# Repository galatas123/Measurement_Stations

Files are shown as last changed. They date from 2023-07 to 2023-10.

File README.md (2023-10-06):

# Measurement_Stations

Features:

   . CO2 Monitoring: Efficiently measures CO2 concentrations, aiding in maintaining a safe indoor environment during pandemic situations.
    
   . Environmental Conditions: Captures data on temperature, humidity, and air pressure, offering a holistic understanding of the indoor atmosphere.
    
   . Data Storage and Accessibility: All the captured metrics are systematically stored in a database, ensuring easy access and analysis.
    
   . Energy Management Insights: The wealth of data collected assists facilities in optimizing energy consumption, especially for heating, leading to cost savings.

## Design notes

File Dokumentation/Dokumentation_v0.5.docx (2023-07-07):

# 1. Ist-Zustand

## 1.1 Funktionsweise

Wird die Messstation eingeschaltet, leuchten ihre LEDs zunächst blau und es wird versucht eine Verbindung zu dem im Arduino-Programm festgelegten WLAN-Netzwerk herzustellen. Sobald die Verbindung hergestellt ist, beginnt der CO2-Sensor damit sich aufzuwärmen, was etwa drei Minuten in Anspruch nimmt.
Wenn der Sensor aufgewärmt ist und die Verbindung zum Netzwerk steht, misst die Station alle 60 Sekunden CO2-Konzentration, Luftdruck, Lufttemperatur und Luftfeuchtigkeit. Die Messwerte werden dann im Anschluss zusammen mit dem Stationsnamen und der Stations-ID über WLAN an einen Datenbankserver gesendet, welcher die Messdaten mit einem Zeitstempel versieht.
Die gesammelten Daten aller Stationen können dann über Grafana eingesehen werden.

## 1.2 Kurzbeschreibungen der Komponenten

Gehäuse | Das Gehäuse einer Messstation besteht jeweils aus einem Bodenstück und einem Deckel die beide mit einem 3D-Drucker aus PLA gedruckt wurden. Das Bodenstück verfügt über eine Schiene, in die die Platine eingeschoben wird. Der Deckel wird ebenfalls einfach auf das Bodenstück mit der Platine gesteckt und durch Reibung gehalten. Wenn der Deckel korrekt aufgesteckt wurde, verhindert er außerdem ein Herausrutschen der Platine aus der Schiene des Bodenstücks. Die Maße eines vollständigen Gehäuses Betragen etwa 42x103x19mm.
Platine | Die Platine besteht aus einem 37x100mm großen Stück Punktrasterplatine mit einem Rastermaß von 2,54mm.
ESP8266 | Der ESP8266 (speziell NodeMCU Lolin v3) ist ein WLAN-fähiger 32-Bit-Mikrocontroller und das Kernstück jeder Messstation.
MH-Z19B | Der MH-Z19B ist ein CO2-Sensor, der die Konzentration von Kohlenstoffdioxid in der Luft mit dem Prinzip der nichtdispersiven Infrarotspektroskopie misst. Für die Kommunikation wird entweder UART oder PWM verwendet.
BME280 | Der BME280 ist ein Temperatur-, Luftfeuchtigkeits- und Luftdrucksensor. Für die Kommunikation wird I²C verwendet.
LED | Der LED-Streifen, welcher entweder an der Messstation direkt oder separat (z.B. über der Station an einer Säule) befestigt ist, besteht aus individuell Programmierbaren WS2812-LEDs und dient zur Anzeige von Grenzwertüberschreitungen der CO2-Konzentration.
Spannungsversorgung | Die gesamte Messstation wird über den Micro-USB-Anschluss des ESP8266 durch ein 5VDC-Netzteil mit Spannung versorgt.

# 2. Soll-Zustand

## 2.1 BME280 ersetzen

Der BME280 soll durch einen genaueren Sensor für das Messen von Lufttemperatur und Luftfeuchtigkeit ersetzt werden.
Ziel hiervon ist, die Messstationen, die zurzeit in der Firma verwendet werden durch die kompakteren und einfacher zu Handhabenden CO2-Messstationen zu ersetzen, ohne zu sehr an der Messgenauigkeit einzubüßen.

## 2.2 Neue Platine mit I²C-Port

Die handgelöteten Lochrasterplatinen der alten Messstationen sollen durch mit EasyEDA entworfene und maschinell hergestellte Platinen ersetzt werden.
Zusätzlich soll anstelle des bisher vorhanden Pin-Headers für den Anschluss der NeoPixel-Streifen ein Port für den Anschluss von I²C-Geräten bzw. Komponenten hinzukommen.

## 2.3 OTA

Jede Messstation soll per OTA (Over the Air) programmiert werden können.
Dies ermöglicht es den Stationen Softwareupdates über das lokale Netzwerk zu erhalten, ohne dass jede Station erst vom Stromnetz getrennt und dann an einen Computer bzw. Laptop angeschlossen werden muss.

## 2.4 Kalibration des MH-Z19B

Das Problem der Kalibration des MH-Z19B soll untersucht bzw. eine Lösung gefunden werden.

## 2.5 Änderungen am Gehäuse

# 3. Entwicklungsschritte

## 3.1 BME 280 ersetzen

Da die Messergebnisse des bisher verwendeten BME280 nicht befriedigend waren, wurde entschieden stattdessen den DHT22 einzusetzen.
Zusätzlich wird der Sensor nun nicht mehr direkt auf der Platine montiert, sondern außerhalb des Gehäuses der Messstation, um Probleme wie die Abwärme des ESP8266 oder die relativ schlechte Durchlüftung des Gehäuseinneren zu umgehen.

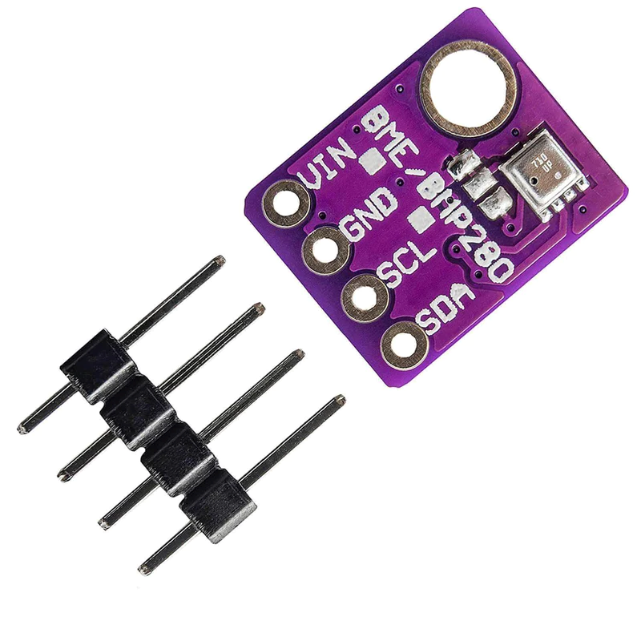
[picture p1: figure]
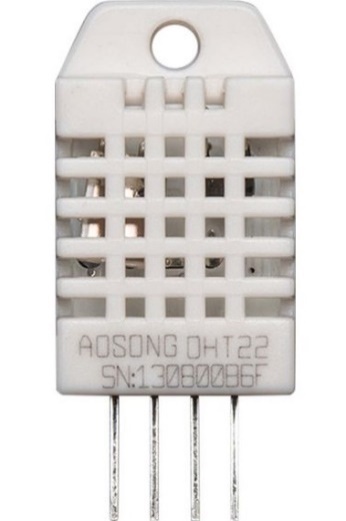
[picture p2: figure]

Abbildung 1: BME280 | Abbildung 2: DHT22

Da der BME280 zur Kommunikation das I²C-Protokoll verwendet und somit zwei Pins des ESP8266 beansprucht, der DHT22 aber nur einen Pin benötigt, weil er ein eigenes One-Wire-Protokoll verwendet, geht der Wechsel auch mit einer Änderung des Platinen Layouts einher: Statt an den Pins D1 und D2 ist der neue Sensor nun lediglich mit Pin D4 verbunden.
Der DHT22 wird nun auch nicht mehr, wie der BME280 in den alten Messstationen innerhalb des Gehäuses auf der Platine montiert, sondern hängt außerhalb und wird nur durch die etwa 10cm lange Verkabelung zwischen Sensor und Platine gehalten. Die bessere Belüftung und die Minimierung der Kontaktfläche zur Messstation sollen den Einfluss der Abwärme des ESP8266 und des MH-Z19B und die damit einhergehenden Messfehler minimieren.

## 3.2 Neue Platine

Die äußeren Dimensionen der alten und der neuen Platine sind bis auf einige zehntel Millimeter identisch, was die Wiederverwendung von bereits bestehenden Gehäuseteilen, speziell dem Bodenstück, mit geringfügigen Änderungen zulässt und nebenher den Material- und Zeitaufwand für den 3D-Druck so gering wie möglich hält.
Die Anordnung der Komponenten auf den beiden Platinen ist sehr ähnlich, da die neue Platine eine Weiterentwicklung dessen ist, was Anfangs lediglich eine 1:1 Portierung der Alten in die Toolchain von EasyEDA war.
Auf der neuen Platine werden nur noch der ESP8266, der MH-Z19B und die drei Wire-To-Board Sockel direkt verlötet. Der DHT22, der NeoPixel-LED-Streifen und weitere I²C Geräte oder Komponenten können einfach an- oder abgesteckt werden, was die Arbeit an den Stationen zu Montage-, Demontage- oder auch Wartungszwecken vereinfacht.
Eine potenzielle Fehlerquelle der alten Version war zum Beispiel die Anbringung des LED-Streifens. Dieser war über kurze Verbindungskabel in der Nähe des Micro-USB-Ports direkt auf drei nach unten verlaufenden Leiterbahnen auf der Rückseite der Platine aufgelötet. Ungenaues Arbeiten oder verschleiß der Kabel bzw. Lötstellen konnte den Stromkreis unterbrechen oder im schlimmsten fall Kurzschließen.
Bei der Handhabung der alten Stationen konnte der LED-Streifen ebenfalls ein Hindernis darstellen, da er fest mit der Platine verlötet und mit dem Gehäusedeckel verklebt war.

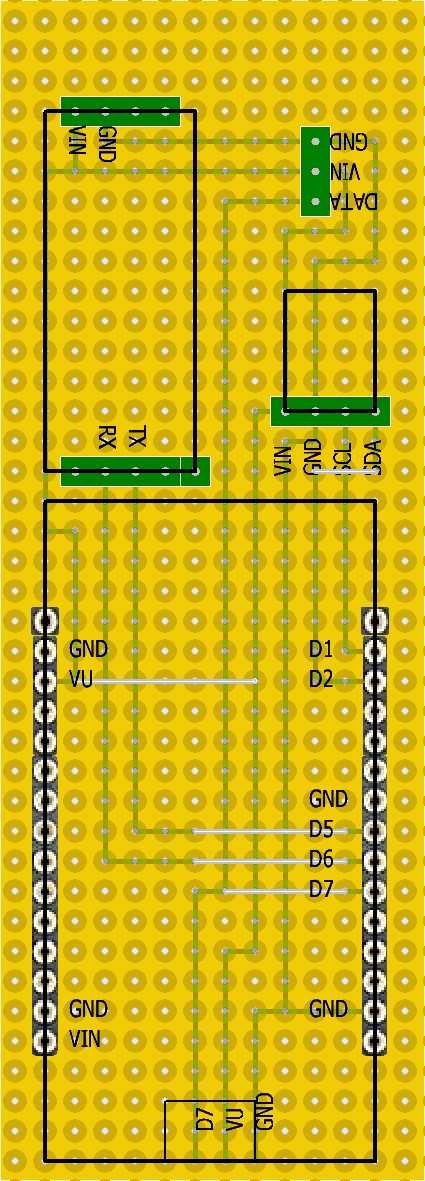
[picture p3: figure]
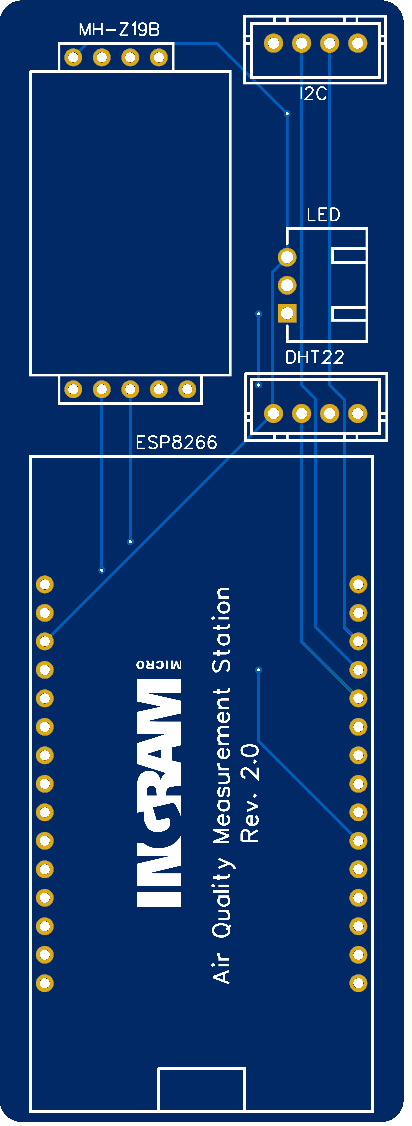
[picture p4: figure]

Abbildung 3: Rev 1.x Platine | Abbildung 4: Rev 2.x Platine

Bei unvorsichtiger Handhabung konnte es leicht zu Beschädigungen an den Kabeln, Lötstellen oder zum Ablösen des LED-Streifens vom Gehäusedeckel kommen.
Die alte Platine hatte theoretisch zwar ebenfalls eine Möglichkeit den LED-Streifen an- und abzustecken in Form eines male pin headers, aber in der Praxis verlangte das Anschließen Fingerspitzengefühl, das Wissen welches Kabel mit welchem Pin verbunden werden muss und die Hoffnung, dass sich die Kabel nicht von selbst durch die äußert geringe Reibung zum header pin lösen; die Buchsen und Stecker der neuen Platine lassen, sofern nicht zum Beispiel der DHT22 an die baugleiche I²C-Schnittstelle angesteckt wird, keine Verpolung oder ein unbeabsichtigtes herausfallen des Steckers zu.

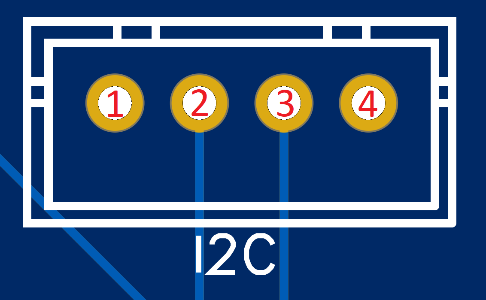
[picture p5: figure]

| Anschluss für I²C-Bus und VU 1. GND 2. SCL 3. SDA 4. VU*

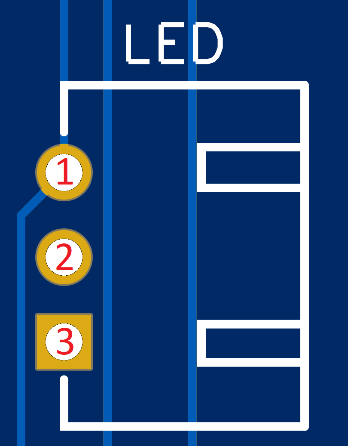
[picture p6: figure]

| Anschluss für NeoPixel 1. VU* 2. Data 3. GND

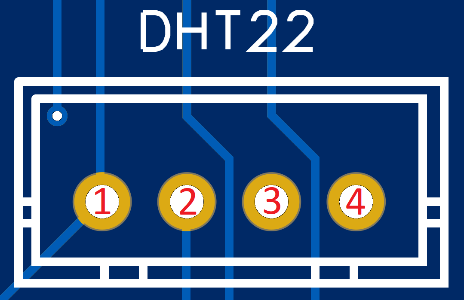
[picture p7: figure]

| Anschluss für DHT22 1. VU* 2. Data 3. NC 4. GND

* Bemerkung: Alle VU-Pins sind direkt mit der Micro-USB Buchse des ESP8266 verbunden, die anliegende Spannung ist vom Verwendeten Netzteil und dessen Auslastung abhängig.

V 0.3 Ingram Micro Services GmbH 1 / 2

Air Quality Measurement Station Rev 2.x

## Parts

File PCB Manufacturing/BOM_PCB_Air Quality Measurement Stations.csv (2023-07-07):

ID | Name | Designator | Footprint | Quantity | Manufacturer Part | Manufacturer | Supplier | Supplier Part | Price | Pins | 3DModel | Contributor | link
1 | M2501V-04P | I2C,DHT22 | CONN-TH_4P-P2.50_M2501V-04P | 2 | M2501V-04P | XFCN(兴飞) | LCSC | C492458 | 0.021 | 4 | CONN-TH_4P-P2.50_M2501V-04P | lcsc | https://atta.szlcsc.com/upload/public/pdf/source/20200309/C492458_8F7167A868D32DBA88041FC5B3C21C86.pdf
2 | ESP8266_NodeMCU_v3 | ESP8266 | ESP8266_NODEMCU_V3 | 1 |  |  |  |  |  | 30 |  | falkpetersen
3 | X8821WR-03S-N0SN | LED | CONN-TH_3P-P2.50_X8821WR-03S-N0SN | 1 | X8821WR-03S-N0SN | XKB Enterprise | LCSC | C388740 | 0.025 | 3 | CONN-TH_XH2.50-WI-3P | LCSC | https://lcsc.com/product-detail/New-Arrivals_XKB-Enterprise-X8821WR-03S-N0SN_C388740.html
4 | MH-Z19B | MH-Z19B | MH-Z19B | 1 |  |  |  |  |  | 9 |  | falkpetersen

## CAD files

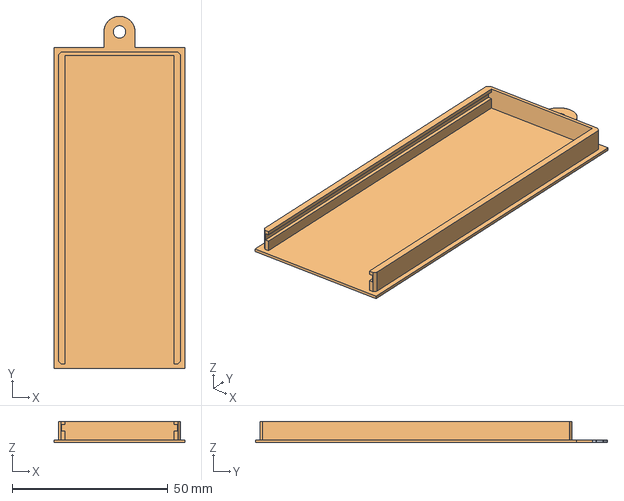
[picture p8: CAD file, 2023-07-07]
3D printed Housing/cad/bottom_v7.FCStd
42.0 x 113.0 x 6.80 mm
Body (Meshed)

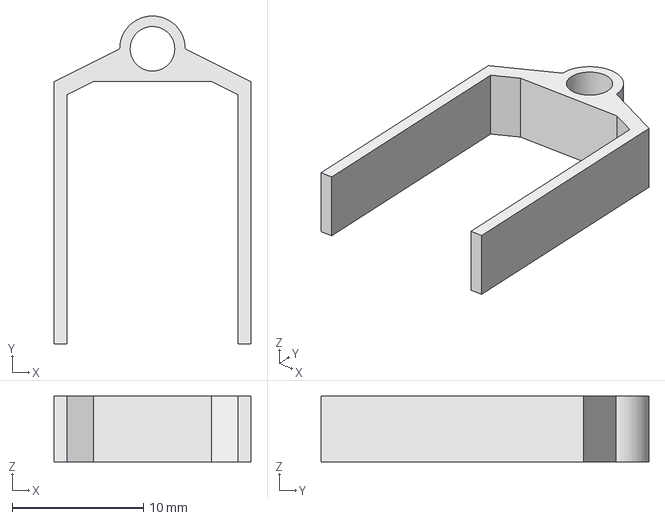
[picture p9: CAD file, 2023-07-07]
3D printed Housing/cad/dht_spacer.FCStd
15.0 x 25.0 x 5.00 mm

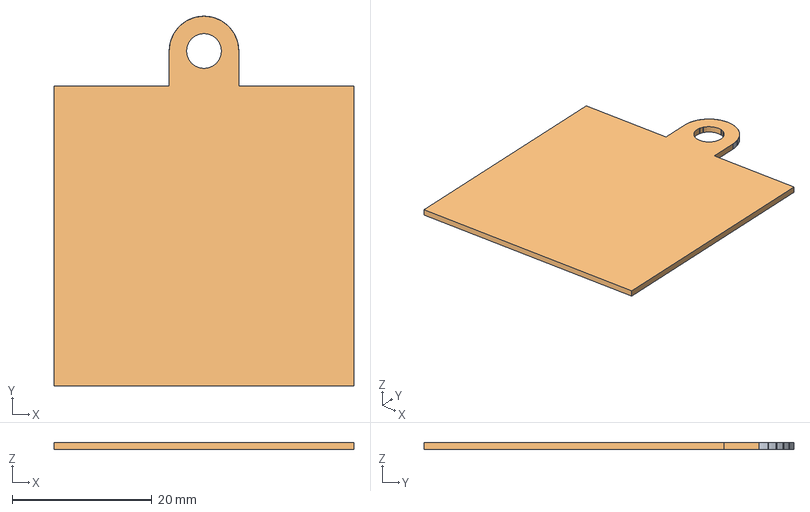
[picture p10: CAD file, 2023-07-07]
3D printed Housing/cad/adapter_v1.FCStd
43.0 x 53.0 x 1.00 mm
Pad (Meshed)

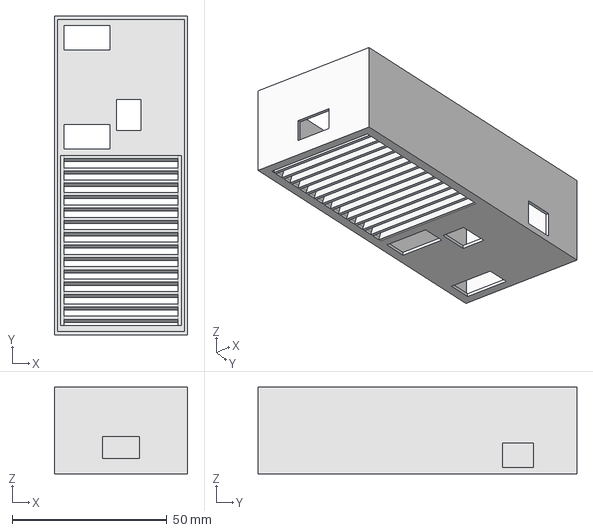
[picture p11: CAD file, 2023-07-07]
3D printed Housing/cad/top_v9.FCStd
43.0 x 103.0 x 28.0 mm

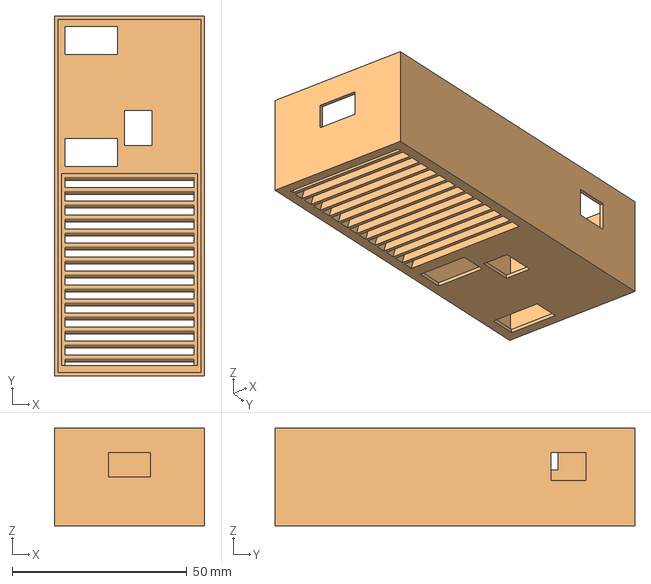
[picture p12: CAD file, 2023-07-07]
3D printed Housing/cad/top_v9_alt.FCStd
43.0 x 103.0 x 28.0 mm
Body (Meshed)

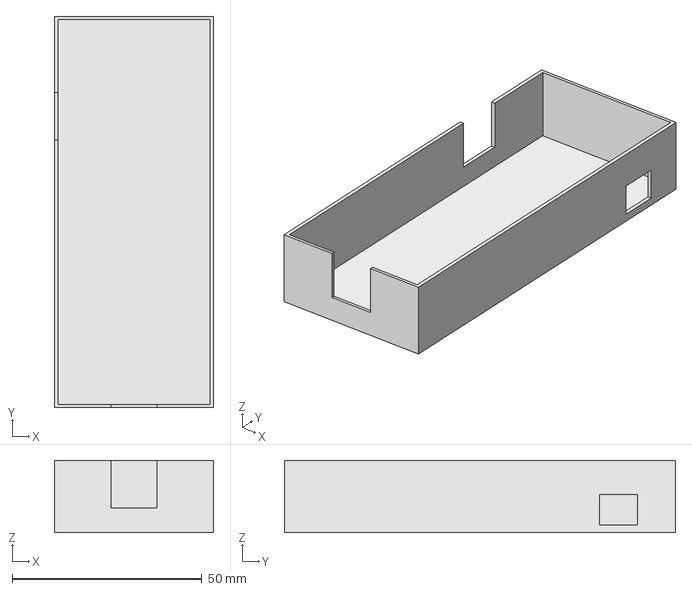
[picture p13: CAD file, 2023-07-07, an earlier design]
3D printed Housing/cad/top_v8.FCStd
42.0 x 103.0 x 19.0 mm

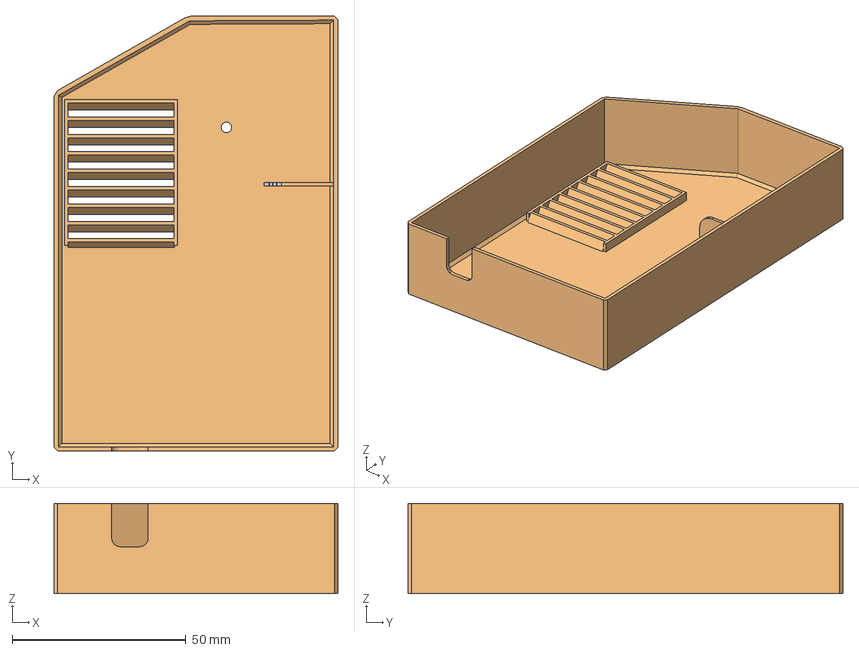
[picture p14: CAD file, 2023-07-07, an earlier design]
3D printed Housing/cad/top_v6.FCStd
81.5 x 125.0 x 26.0 mm
Chamfer009 (Meshed)

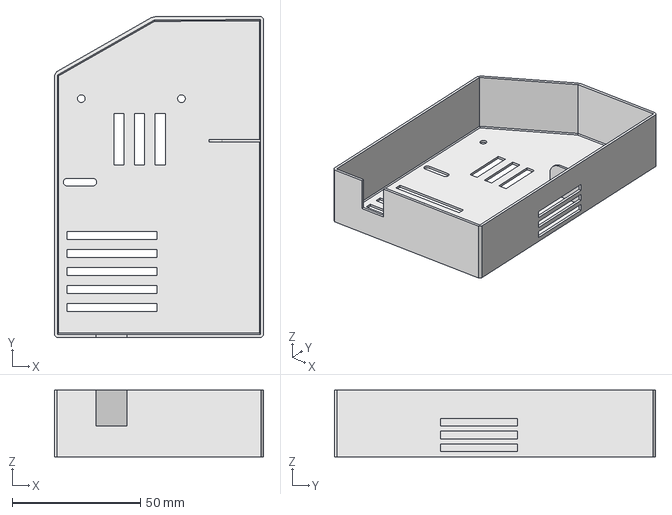
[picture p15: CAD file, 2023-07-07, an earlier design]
3D printed Housing/cad/top_v7 - Kopie.FCStd
81.5 x 125.0 x 26.0 mm

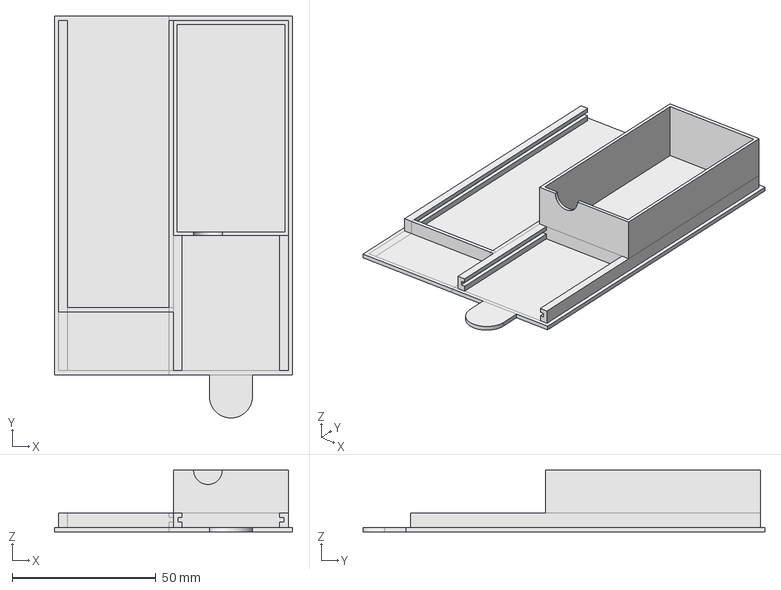
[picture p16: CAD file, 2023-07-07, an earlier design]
3D printed Housing/cad/bottom_v3.FCStd
83.0 x 140.0 x 21.5 mm

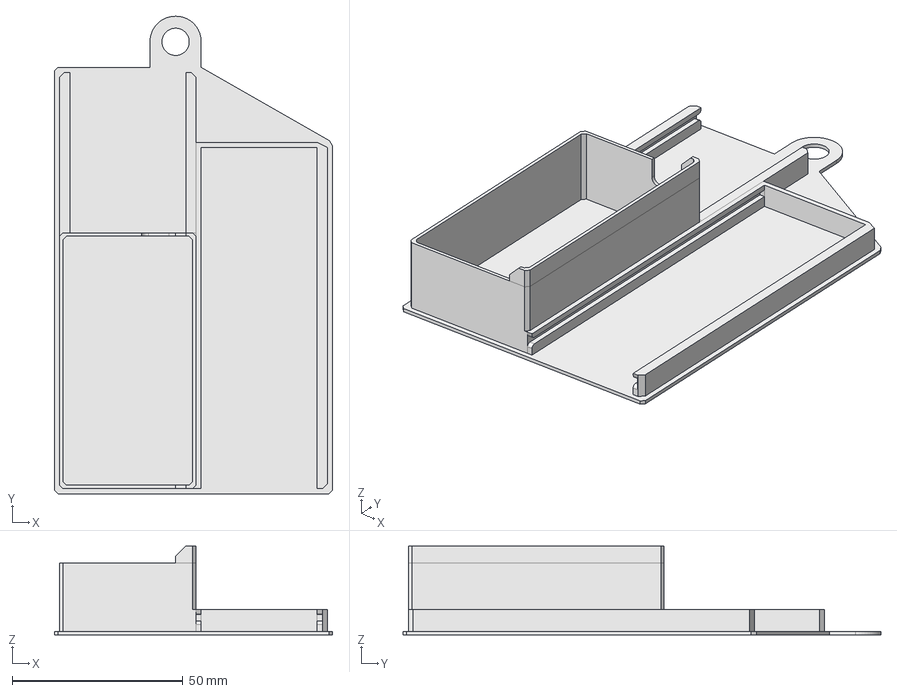
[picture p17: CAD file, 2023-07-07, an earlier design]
3D printed Housing/cad/bottom_v6.FCStd
81.5 x 140.0 x 26.0 mm

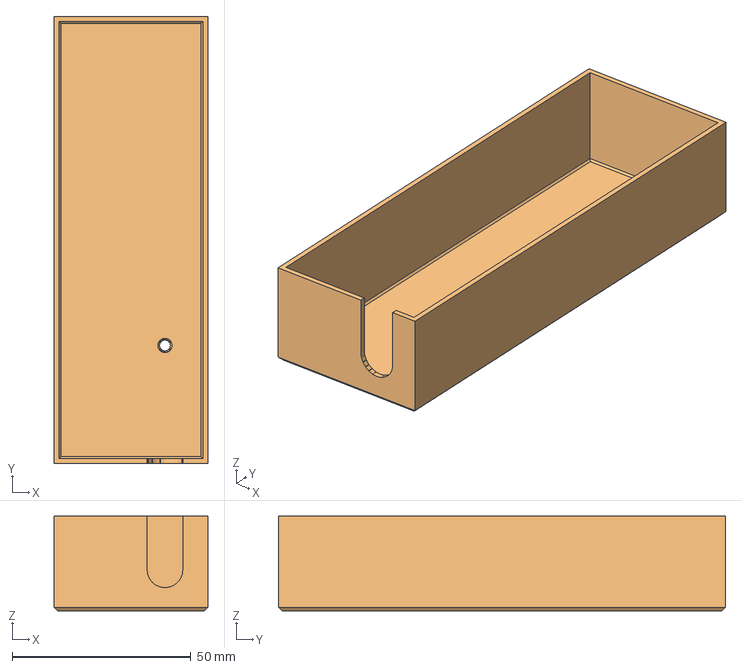
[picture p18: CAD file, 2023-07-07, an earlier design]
3D printed Housing/cad/top_v2.FCStd
43.0 x 125.0 x 26.5 mm
Chamfer001 (Meshed)

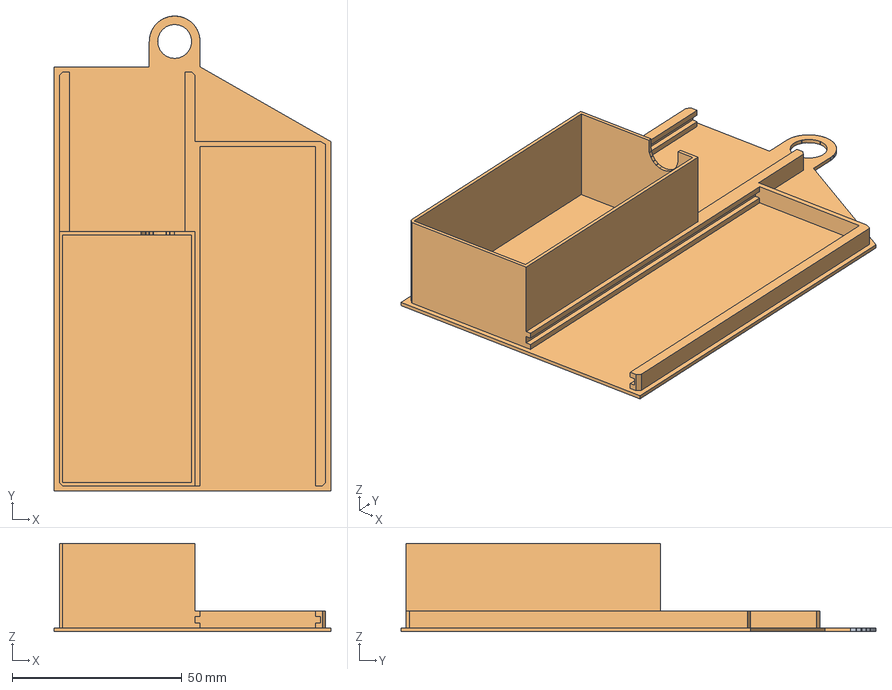
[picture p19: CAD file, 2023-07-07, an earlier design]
3D printed Housing/cad/bottom v4.FCStd
81.5 x 140.0 x 26.0 mm
Chamfer003 (Meshed)

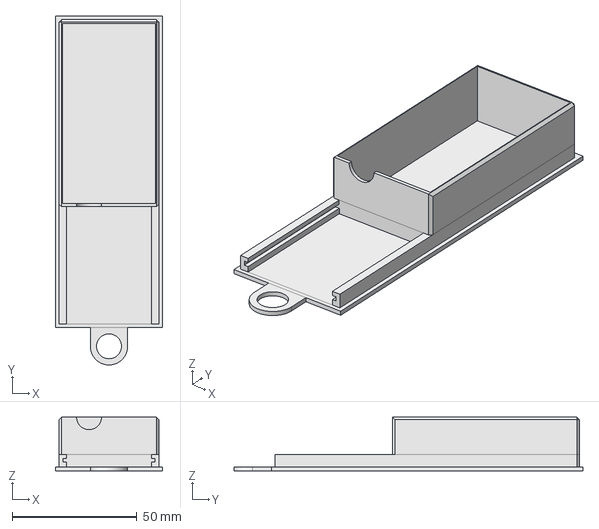
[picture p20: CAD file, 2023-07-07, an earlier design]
3D printed Housing/cad/bottom_v2.FCStd
43.0 x 140.0 x 21.5 mm

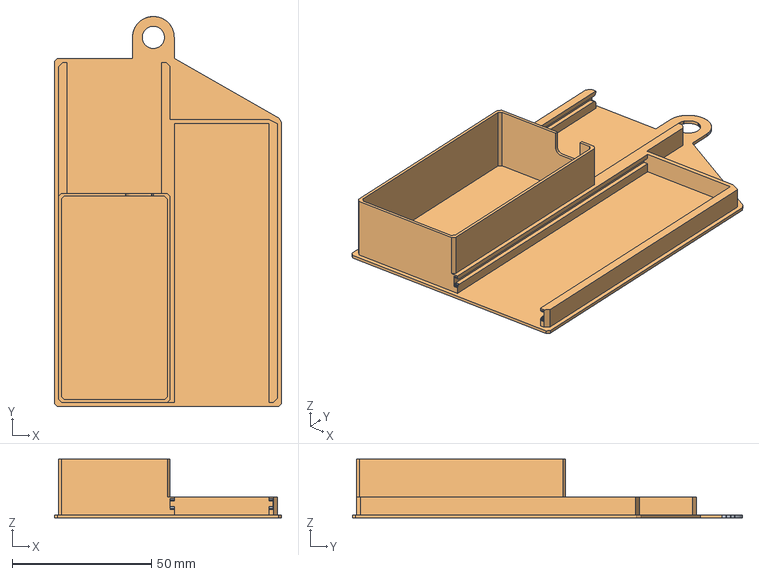
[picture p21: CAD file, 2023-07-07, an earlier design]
3D printed Housing/cad/bottom_v5.FCStd
81.5 x 140.0 x 21.0 mm
Chamfer013 (Meshed)

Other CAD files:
3D printed Housing/cad/bottom_v1.FCStd
3D printed Housing/cad/top_v1.FCStd
3D printed Housing/cad/top_v4.FCStd
3D printed Housing/cad/top_v5.FCStd
3D printed Housing/stl/adapter_v1.stl
3D printed Housing/stl/bottom_v1.stl
3D printed Housing/stl/bottom_v4.stl
3D printed Housing/stl/bottom_v5.stl
3D printed Housing/stl/bottom_v6.stl
3D printed Housing/stl/bottom_v7.stl
3D printed Housing/stl/dht_spacer.stl
3D printed Housing/stl/top_v4.stl
3D printed Housing/stl/top_v5.stl
3D printed Housing/stl/top_v6.stl
3D printed Housing/stl/top_v7.stl
3D printed Housing/stl/top_v9.stl
3D printed Housing/stl/top_v9_alt.stl

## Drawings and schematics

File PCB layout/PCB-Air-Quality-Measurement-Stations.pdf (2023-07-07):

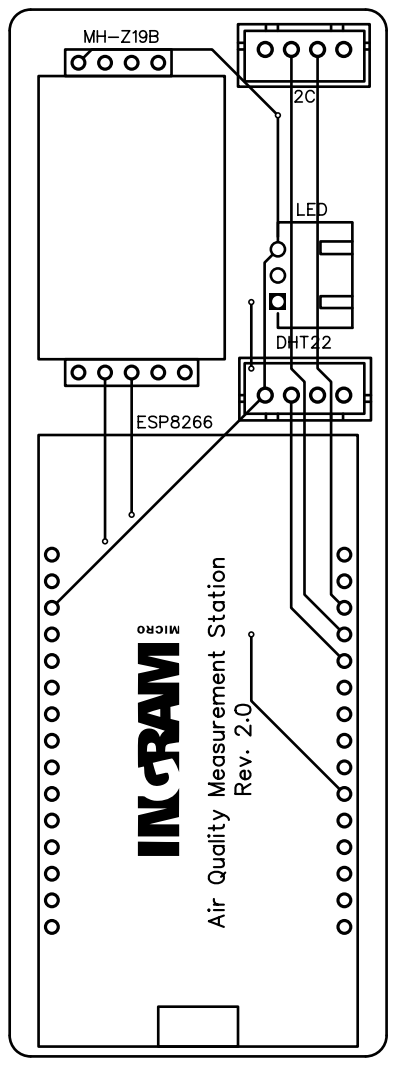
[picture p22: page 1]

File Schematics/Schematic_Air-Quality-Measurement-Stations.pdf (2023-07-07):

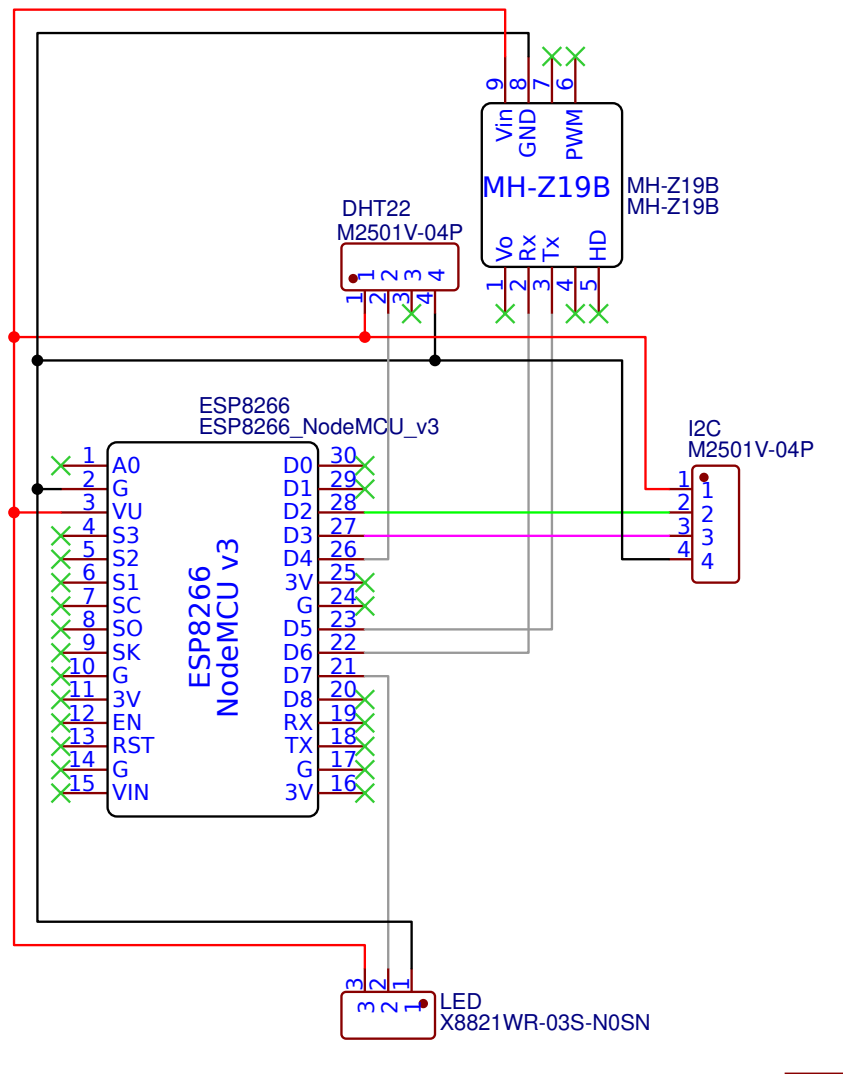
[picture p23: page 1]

Company: Ingram Micro Services GmbH

Drawn By: Anil Chikmet Oglou

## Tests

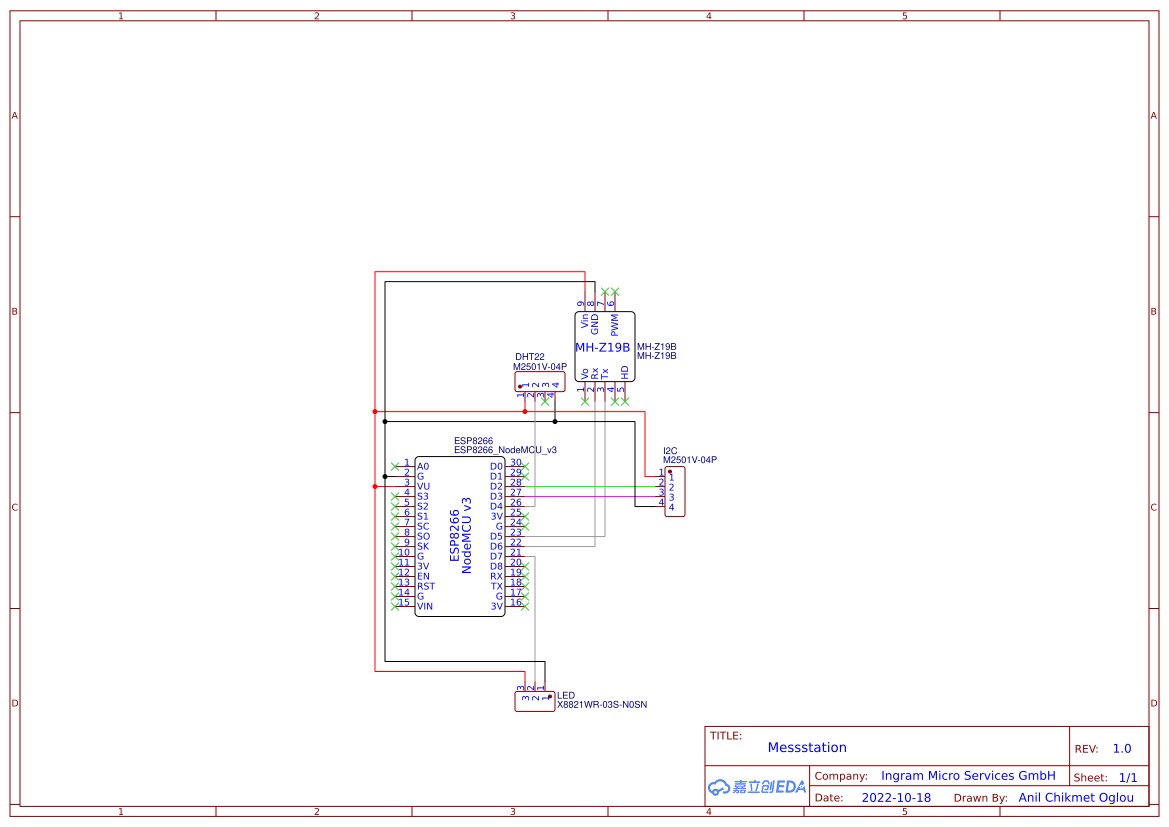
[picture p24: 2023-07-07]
Schematics/Schematic_Air-Quality-Measurement-Stations.png

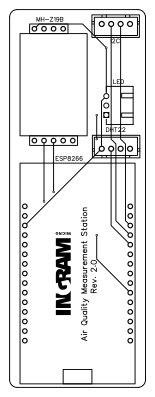
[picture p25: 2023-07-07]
PCB layout/PCB-Air-Quality-Measurement-Stations.png

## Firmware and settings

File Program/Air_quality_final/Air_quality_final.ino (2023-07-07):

//~~~~~~~~~~~~~~~~~~~~~~~~~~~~~~~~MASTER CONFIG~~~~~~~~~~~~~~~~~~~~~~~~~~~~~~~~

#define WIFI_SSID             "IMSFL"               //SSID of network to connect to
#define WIFI_PWD              "V2$2uDY#P4"          //Password of the network
#define WIFI_RESET_TIME       10                    //Time in minutes until restart if WiFi isn't connected

#define DB_SP_ADDRESS         172,17,11,129         //Special Projects internal Database
#define DB_ADDRESS            172,17,0,91           //Database server IP address
#define DB_USER               "klima"               //Database username
#define DB_PWD                "klima_2020#"         //Database password
#define DB_DEFAULT            "klimadaten"          //Default database

#define STATION_NAME          "Halle_E"                 //Name of this station
#define STATION_ID            11                    //ID of this station

#define TYPE_SENSOR           "DHT"                 //Use "BME" or "DHT" to choose between BME280 and DHT22 sensors

#define NUMPIXELS             8                     //Number of NeoPixel LEDs
#define COLOR_BRT             0.25                  //Brightness multiplier for NeoPixel LEDs (0.0 - 1.0) 
#define THRESHOLD_CO2_UPPER   700                   //If CO2 exceeds this value the NeoPixels will shine red
#define THRESHOLD_CO2_LOWER   600                   //If CO2 is lower than this value the NeoPixels will shine green
#define THRESHOLD_ERRORS      10                    //Number of -3 returns after which a restart occurs

#define ADDRESS_NTP           "0.de.pool.ntp.org"   //Address of NTP server to fetch date / time information from
#define CALIBRATION_BEGIN     3                     //Beginning of calibration time frame in hours
#define CALIBRATION_END       6                     //End of calibration time frame in hours

#define ENABLE_WARMUP         true                 //Allow MH-Z19B to warum up before entering the main loop?

#define OTA_NAME              "CO2_Halle_E"             //Station hostname for OTA


//~~~~~~~~~~~~~~~~~~~~~~~~~~~~~~~~LIBRARIES~~~~~~~~~~~~~~~~~~~~~~~~~~~~~~~~

#include <DHT.h>
#include <DHT_U.h>
#include <ErriezMHZ19B.h>
#include <SoftwareSerial.h>
#include <ESP8266WiFi.h>
#include <WiFiUdp.h>
#include <Wire.h>
#include <Adafruit_NeoPixel.h>
#include <MySQL_Connection.h>
#include <MySQL_Cursor.h>
#include <Adafruit_Sensor.h>
#include <Adafruit_BME280.h>
#include <stdio.h>
#include <NTPClient.h>
#include <ArduinoOTA.h>


//~~~~~~~~~~~~~~~~~~~~~~~~~~~~~~~~PIN CONFIG~~~~~~~~~~~~~~~~~~~~~~~~~~~~~~~~

#define PIN_MHZ19B_TX   D5
#define PIN_MHZ19B_RX   D6
#define PIN_LED         D7
#define PIN_DHT         D4


//~~~~~~~~~~~~~~~~~~~~~~~~~~~~~~~~SENSOR, LED, WIFI CONFIG & INIT~~~~~~~~~~~~~~~~~~~~~~~~~~~~~~~~

#define MHZ19B_DETECT_DELAY 1000
#define MHZ19B_WARMUP_DELAY 2000

Adafruit_BME280 bme;
DHT dht(PIN_DHT, DHT22);

SoftwareSerial mhzSerial(PIN_MHZ19B_TX, PIN_MHZ19B_RX);
ErriezMHZ19B mhz19b(&mhzSerial);
WiFiClient client;
Adafruit_NeoPixel pixels (NUMPIXELS, PIN_LED, NEO_GRB + NEO_KHZ800);

byte errors = 0;


//~~~~~~~~~~~~~~~~~~~~~~~~~~~~~~~~NTP & CALIBRATION~~~~~~~~~~~~~~~~~~~~~~~~~~~~~~~~

WiFiUDP ntpUDP;
NTPClient timeClient(ntpUDP, ADDRESS_NTP, 3600, 60000);


byte calibrationTimeFrame[2] = {CALIBRATION_BEGIN,  CALIBRATION_END};

bool isCalibrated = false;
bool calibrationValid = false;

//~~~~~~~~~~~~~~~~~~~~~~~~~~~~~~~~MEASUREMENTS~~~~~~~~~~~~~~~~~~~~~~~~~~~~~~~~

int16_t CO2;
float temperature, humidity, pressure = 0.0f;


//~~~~~~~~~~~~~~~~~~~~~~~~~~~~~~~~WIFI CONFIG~~~~~~~~~~~~~~~~~~~~~~~~~~~~~~~~

const char* ssid = WIFI_SSID;
const char* pass = WIFI_PWD;
const char* station = STATION_NAME;
const int id = STATION_ID;

unsigned long wifiDownTime;

//~~~~~~~~~~~~~~~~~~~~~~~~~~~~~~~~MYSQL CONFIG & INIT~~~~~~~~~~~~~~~~~~~~~~~~~~~~~~~~

IPAddress server_addr(DB_ADDRESS);
IPAddress SP_DB_addr(DB_SP_ADDRESS);

char dbUser[] = DB_USER;
char dbPassword[] = DB_PWD;
char default_db[] = DB_DEFAULT;

MySQL_Connection conn((Client *)&client);
MySQL_Cursor cur = MySQL_Cursor(&conn);

char statement[200];

//~~~~~~~~~~~~~~~~~~~~~~~~~~~~~~~~COLORS~~~~~~~~~~~~~~~~~~~~~~~~~~~~~~~~

#define COLOR_RED       0xFF, 0x00, 0x00
#define COLOR_GREEN     0x00, 0xFF, 0x00
#define COLOR_BLUE      0x00, 0x00, 0xFF
#define COLOR_YELLOW    0xFF, 0x82, 0x00
#define COLOR_TURQUOISE 0x30, 0xD5, 0xC8
#define COLOR_LILA      0xFF, 0x00, 0xFF
#define COLOR_WEISS     0xFF, 0xFF, 0xFF
#define OFF             0x00, 0x00, 0x00


bool dbConnected;


//~~~~~~~~~~~~~~~~~~~~~~~~~~~~~~~~FUNCTIONS~~~~~~~~~~~~~~~~~~~~~~~~~~~~~~~~

void setLED(byte r, byte g, byte b)
{
  pixels.clear();

  for (int i = 0; i < NUMPIXELS; i++)
  {
    pixels.setPixelColor(i, pixels.Color(r * COLOR_BRT, g * COLOR_BRT, b * COLOR_BRT));
    pixels.show();
  }
}

void mySQLTest(char query[])
{
  if (conn.connect(SP_DB_addr, 3306, dbUser, dbPassword, default_db))
  {
    Serial.println(F("Connected to Special Projects database."));
    cur.execute(query);
    cur.close();
    conn.close();
  }
  else
  {
    Serial.println(F("Error: Can't connect to Special Projects database."));
  }
}

void mySQL(char query[])
{
  if (conn.connect(server_addr, 3306, dbUser, dbPassword, default_db))
  {
    dbConnected = true;
    Serial.println(F("Connected to database."));
    cur.execute(query);
    cur.close();
    conn.close();
  }
  else
  {
    dbConnected = false;
    Serial.println(F("Error: Can't connect to database."));
  }
}


int16_t readCo2()
{
  int16_t result;

  if (mhz19b.isReady())
  {
    result = mhz19b.readCO2();
  }

  return result;
}

void getData()
{
  CO2 = readCo2();

  if(CO2 == -3)
    errors++;
  else
    errors = 0;

  if(errors >= THRESHOLD_ERRORS)
    ESP.restart();

  if (TYPE_SENSOR == "BME")
  {
    temperature = bme.readTemperature();
    humidity = bme.readHumidity();
  }
  else if (TYPE_SENSOR == "DHT")
  {
    temperature = dht.readTemperature();
    humidity = dht.readHumidity();
  }
  else
  {
    temperature = 0.0f;
    humidity = 0.0f;
  }

  Serial.print("\nCO2:\t\t");
  Serial.print(CO2);
  Serial.print("ppm\nTemperature:\t");
  Serial.print(temperature);
  Serial.print("°C\nHumidity:\t");
  Serial.print(humidity);
  Serial.println("%");
}


//~~~~~~~~~~~~~~~~~~~~~~~~~~~~~~~~SETUP & LOOP~~~~~~~~~~~~~~~~~~~~~~~~~~~~~~~~

void setup()
{
  Serial.begin(115200);

  mhzSerial.begin(9600);
  pixels.begin();
  setLED(COLOR_BLUE);

  if (TYPE_SENSOR == "BME")
  {
    bme.begin(0x76);
  }
  else if (TYPE_SENSOR == "DHT")
  {
    dht.begin();
  }

  mhz19b.setAutoCalibration(false);
  Serial.print("\nAutomatic Baseline Calibration turned OFF.\n");

  WiFi.begin(ssid, pass);

  while (WiFi.status() != WL_CONNECTED)
  {
    Serial.println(F("Connecting..."));

    delay(2000);
  }

  Serial.print(F("\nIP Adress:\t"));
  Serial.println(WiFi.localIP());
  Serial.print(F("MAC Address:\t"));
  Serial.println(WiFi.macAddress());
  Serial.print("Station name:");
  Serial.println(station);

  //ARDUINO OTA BEGIN

  ArduinoOTA.setHostname(OTA_NAME);

  ArduinoOTA.onStart([]() {
    String type;
    if (ArduinoOTA.getCommand() == U_FLASH)
      type = "sketch";
    else // U_SPIFFS
      type = "filesystem";

    // NOTE: if updating SPIFFS this would be the place to unmount SPIFFS using SPIFFS.end()
    Serial.println("Start updating " + type);
  });
  ArduinoOTA.onEnd([]() {
    Serial.println("\nEnd");
  });
  ArduinoOTA.onProgress([](unsigned int progress, unsigned int total) {
    Serial.printf("Progress: %u%%\r", (progress / (total / 100)));
  });
  ArduinoOTA.onError([](ota_error_t error) {
    Serial.printf("Error[%u]: ", error);
    if (error == OTA_AUTH_ERROR) Serial.println("Auth Failed");
    else if (error == OTA_BEGIN_ERROR) Serial.println("Begin Failed");
    else if (error == OTA_CONNECT_ERROR) Serial.println("Connect Failed");
    else if (error == OTA_RECEIVE_ERROR) Serial.println("Receive Failed");
    else if (error == OTA_END_ERROR) Serial.println("End Failed");
  });
  ArduinoOTA.begin();
  Serial.println("Ready");
  Serial.print("IP address: ");
  Serial.println(WiFi.localIP());

  //ARDUINO OTA END

  timeClient.begin();

  while (!mhz19b.detect())
  {
    Serial.println(F("Detecting MH-Z19B sensor..."));

    delay(2000);
  }


  if (ENABLE_WARMUP)
  {
    while (mhz19b.isWarmingUp())
    {
      Serial.println(F("MH-Z19B warming up..."));

      delay(2000);
    }
  }

  mhz19b.setRange2000ppm();

  Serial.print(F("\nRange:\t"));
  Serial.print(mhz19b.getRange());
  Serial.println(F("ppm"));

  if (conn.connect(server_addr, 3306, dbUser, dbPassword, default_db))
    dbConnected = true;
}

void loop()
{
  ArduinoOTA.handle();

  if (millis() % 60000 == 0)
  {
    //Calibration

    timeClient.update();
    byte currentHours = (byte)timeClient.getHours();

    if (currentHours >= calibrationTimeFrame[0] && currentHours <= calibrationTimeFrame[1])
    {
      if (!isCalibrated)
      {
        mhz19b.startZeroCalibration();
        isCalibrated = true;
        calibrationValid = true;
        Serial.print(F("\nBaseline calibraton done.\n\n"));
      }
    }
    else
    {
      isCalibrated = false;
      Serial.print(F("\nOutside of calibration timeframe.\n\n"));
    }


    //Get Measurements

    getData();


    //Upload measurements to database

    sprintf(statement, "INSERT INTO co2 (device, date_entry, co2, temperature, air_humidity, air_pressure) VALUES ('%d', now(), '%d', '%f', '%f', '%f')",
            id, CO2, temperature, humidity, pressure);
    Serial.println(statement);

    mySQL(statement);
    mySQLTest(statement);
  }

  if (millis() % 5000 == 0)
  {
    if(WiFi.status() != WL_CONNECTED)
    {
      Serial.print(F("\nWifi Connection lost ("));
      Serial.print(wifiDownTime / 1000);
      Serial.print(F(" s). Restart after "));
      Serial.print(WIFI_RESET_TIME);
      Serial.print(F(" m.\n"));
      
      if(millis() - wifiDownTime >= WIFI_RESET_TIME * 60 * 1000)
        ESP.restart();
    }
    else
    {
      wifiDownTime = millis();
    }
    
    if (!dbConnected || (WiFi.status() != WL_CONNECTED))
    {
      for (int i = 0; i < 4; i++)
      {
        if (!dbConnected)
        {
          if (WiFi.status() != WL_CONNECTED)
          {
            setLED(COLOR_TURQUOISE);
          }
          else
            setLED(COLOR_LILA);
        }
        delay(300);
        pixels.clear();
        delay(300);
      }
    }
    
    if (CO2 > THRESHOLD_CO2_UPPER)
      setLED(COLOR_RED);
    else if (CO2 < THRESHOLD_CO2_LOWER)
      setLED(COLOR_GREEN);
    else
      setLED(COLOR_YELLOW);

  }
}
